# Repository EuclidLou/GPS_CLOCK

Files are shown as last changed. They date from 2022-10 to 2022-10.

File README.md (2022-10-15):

# GPS_CLOCK

## GPS授时的迷你时钟
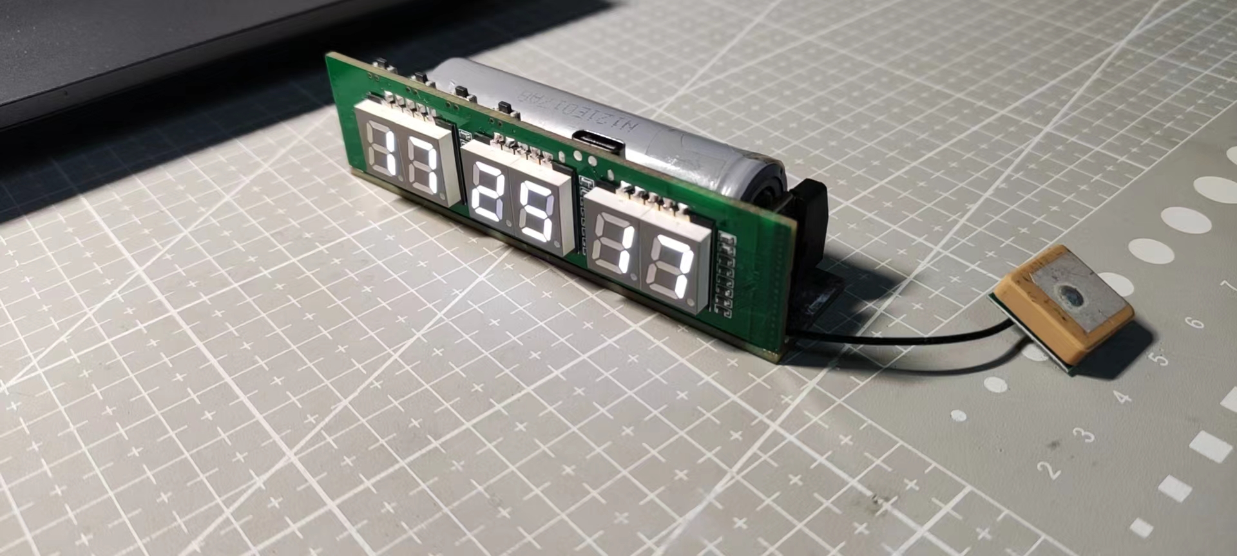
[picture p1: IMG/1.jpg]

## 前言
这是基地招新题目，怎么算成本都要100-200，不如做一个好看点的 <br>
板子的电池接口在两侧，之后会用弹簧连接电池仓 <br>

## 项目结构
|目录|内容|
|---|----|
|PCB_RELEASE|PCB|
|SOFTWARE|程序|
|CAD|外壳|

## 硬件部分
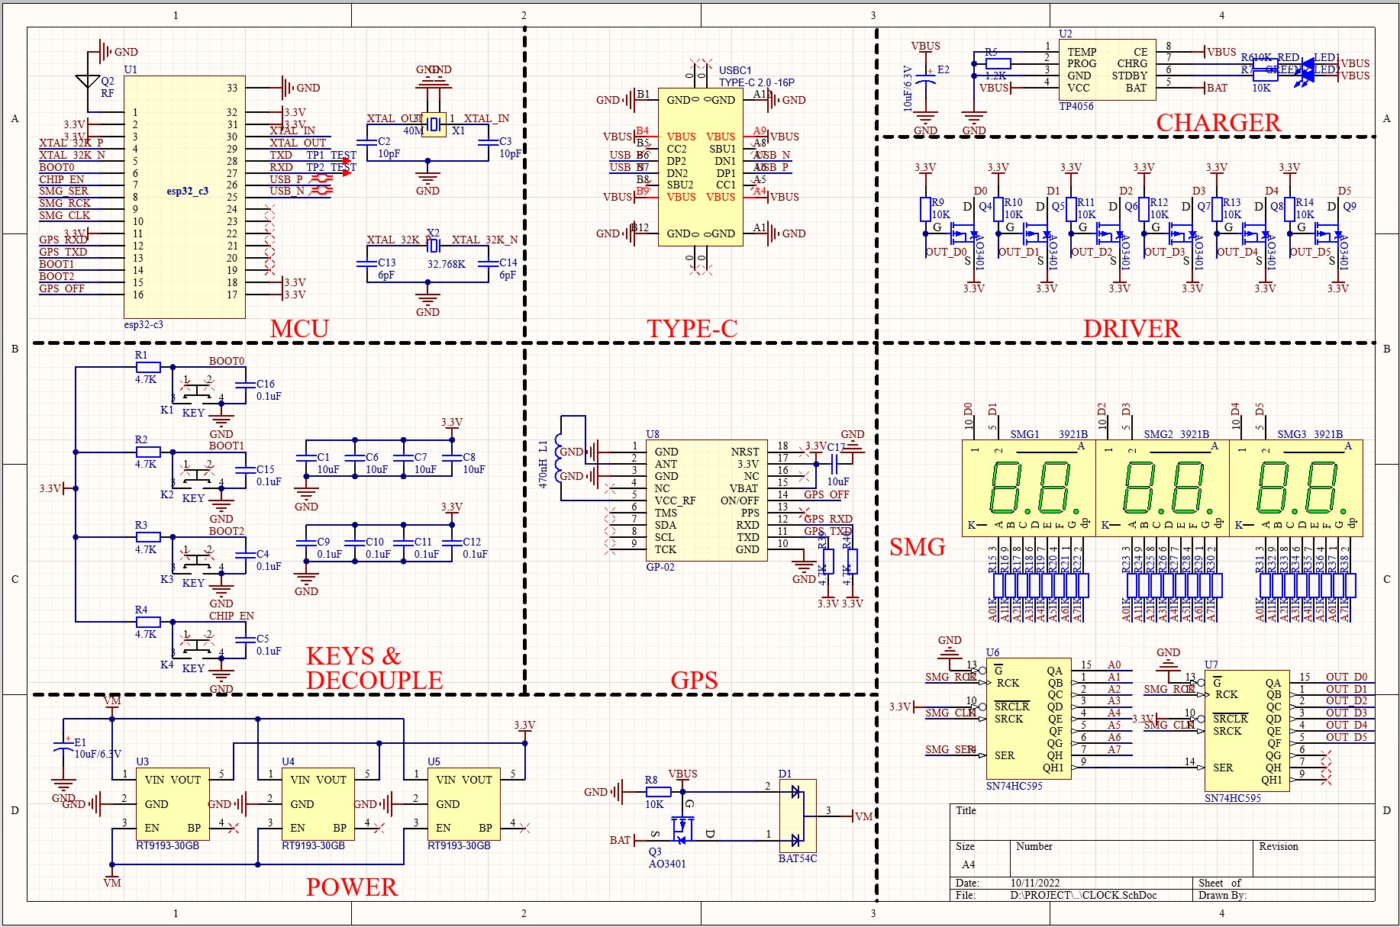
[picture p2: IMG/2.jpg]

主控依然使用ESP32-C3，GPS选用GP-02模块，数码管选了很久，找到了一家专门做贴片数码管的 <br>
译码器使用经典74HC595，担心输出功率不够，加了一级PMOS驱动 <br>
电源管理用的外置TYPE-C供电或一节18650，自动切换电源，并在外接电源时充电 <br>
按键从侧面引出四个，其中三个是可编程的，同时也是BOOT时的STRAPPER引脚(boot选择会自动锁存STRAPPER的值，因此可以复用) <br>
烧录方式通过ESP32内置的USB-JTAG桥，背面也留出了UART0的TEST POINT
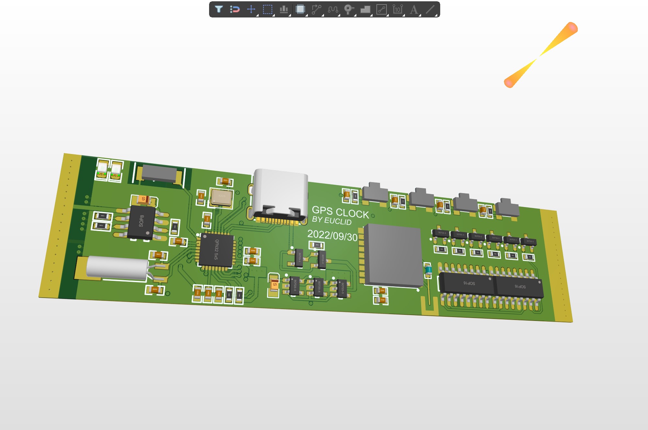
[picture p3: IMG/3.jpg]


## 软件部分
依然通过IDF编写，基于FreeRTOS建立3个线程 <br>
|Thread|Function|
|---|---|
|TaskA |显示时间|
|TaskB |校准时间|
|TaskC |菜单管理|

校准时间通过读取GP-02的 $GNZDA 字段，截取相应时间和日期 <br> 
实测室内冷启动校准耗时30s，热启动4s <br>
菜单正在完善，目前一级菜单KEY0切换显示 时间/日期 ，KEY1、KEY2调整亮度 <br>

## 机械部分
大致设计了一个外壳，把电池座和陶瓷天线都装进去 <br>
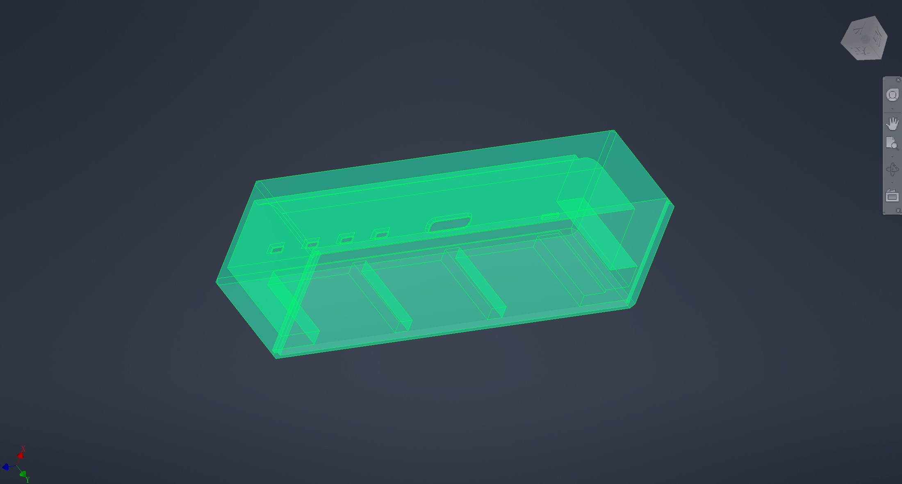
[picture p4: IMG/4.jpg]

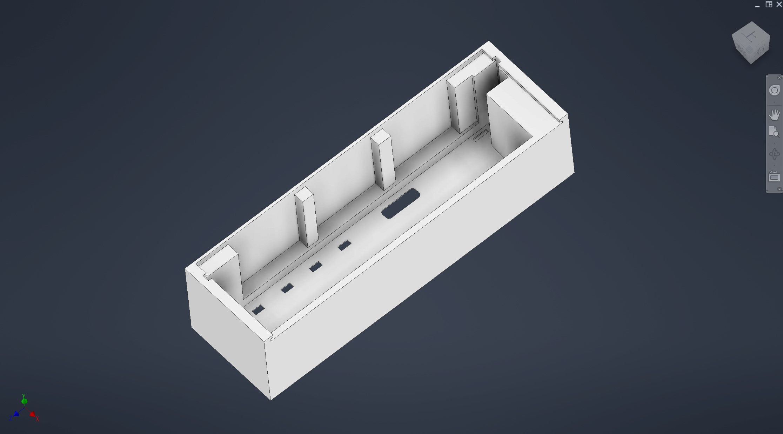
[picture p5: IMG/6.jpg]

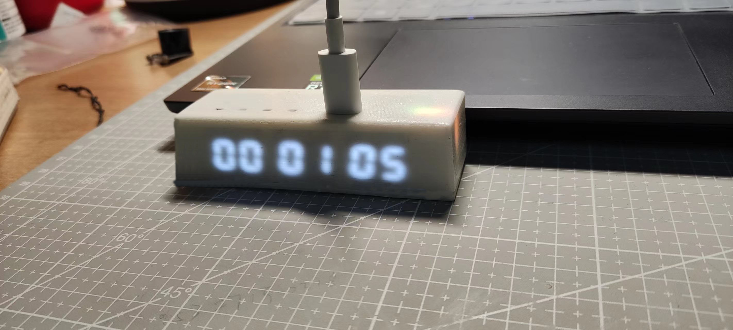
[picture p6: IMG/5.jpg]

外壳思路很美好，实际很拉跨，厚度小于宽度和长度，加上学校3D打印机粗糙的精度，极不符合人类审美，后续可能会改用较薄的锂电芯，并用亚克力板雕刻前后壳，形成三明治结构(或者没有后续，，)。

## 其他
### 关于LDO
ldo部分设计有错误，本来以为rt9193自带输出二极管，实际没有，故不可直接并联 <br>
单个9193可以提供300mA输出，不使用ESP32自带的射频则只需一只ldo
### 关于功耗
整机运行电流(bat端)为70mA左右，其中GPS为40mA，如果接受对时冷启动，满亮度常规运行功耗为30mA。使用18650(5000mAh)可待机约一周。

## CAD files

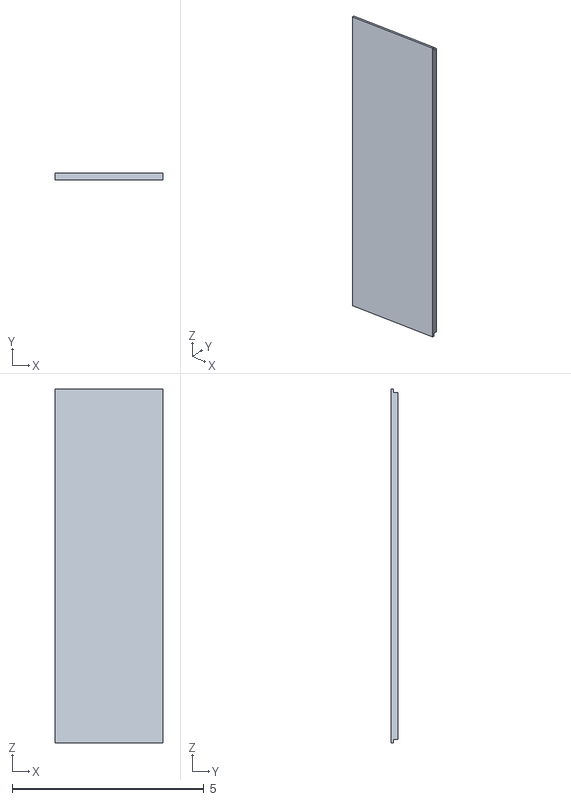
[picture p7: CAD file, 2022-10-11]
CAD/top.stl
2.82 x 0.18 x 9.22

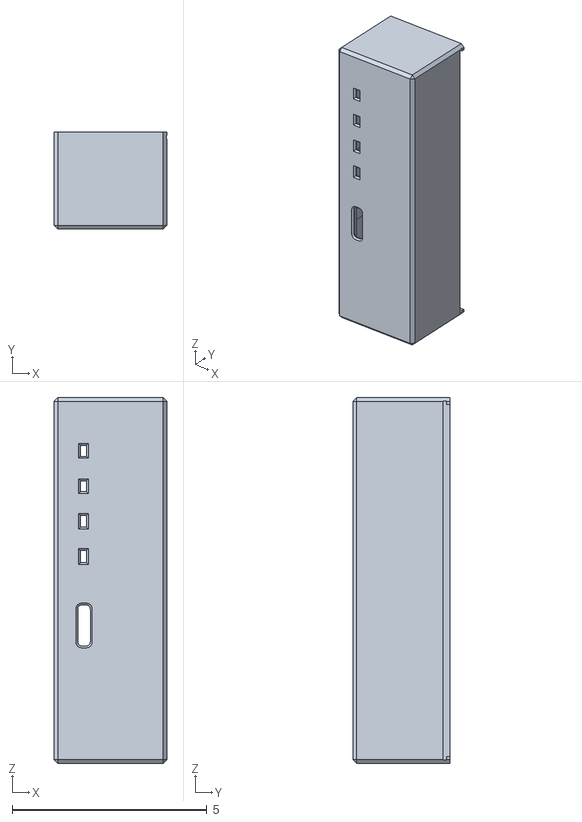
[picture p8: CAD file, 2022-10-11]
CAD/box.stl
2.90 x 2.50 x 9.40

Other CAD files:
CAD/box.ipt
CAD/comb.iam
CAD/top.ipt

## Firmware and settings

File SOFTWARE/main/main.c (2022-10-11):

#include <stdio.h>
#include <stdlib.h>
#include <string.h>
#include <time.h>
#include "driver/gpio.h"
#include "driver/uart.h"
#include "freertos/FreeRTOS.h"
#include "freertos/task.h"
#include "sys/time.h"
#include "esp_log.h"
#include "sdkconfig.h"
#include "driver/gptimer.h"
#include "clock_gpio.h"
#include "main.h"




void Atask(void *pvParameters) {
    uint16_t mode = 0;
    int bright_level = 0;
    time_t trans_time_sec;
    struct tm date_and_time = {0};

    for(;;) {
        xQueuePeek(mode_queue, &mode, 0);
        xQueuePeek(level_queue, &bright_level, 0);
        time(&trans_time_sec);
        localtime_r(&trans_time_sec, &date_and_time);

        if (mode == 0) {
            show_time(date_and_time.tm_hour, date_and_time.tm_min, date_and_time.tm_sec, bright_level);
        }
        else if (mode == 1) {
            show_time(date_and_time.tm_year, date_and_time.tm_mon + 1, date_and_time.tm_mday, bright_level);
        }
         
    }
}

void Btask(void *pvParameters) {
    TickType_t lastwaketime;
    lastwaketime = xTaskGetTickCount();

    time_t trans_time_sec;
    struct tm date_and_time;
    struct timeval val;
    date_and_time.tm_sec   = 0;
    date_and_time.tm_min   = 0;
    date_and_time.tm_hour  = 0;
    date_and_time.tm_year  = 0;
    date_and_time.tm_mon   = 0;
    date_and_time.tm_mday  = 0;
    date_and_time.tm_isdst= -1;

    int init_done = 0;
    int correct_done = 0;
    uint8_t data[1024];
    uint8_t time_data[6];
    uint8_t date_data[6];
    int length = 1024;

    for(int i=60; i>0; i--) { // initialize the time table at the reboot , set 60s timeout.
        length = uart_read_bytes(UART_NUM_1, data, length, 1000);
        for(int pos=0; pos<1000; pos++) {
            if((data[pos] == '$') && (data[pos+1] == 'G') && (data[pos+2] == 'N') && (data[pos+3] == 'Z') && (data[pos+4] == 'D') && (data[pos+5] == 'A') && (data[pos+6] == ',') && (data[pos+7] < 58) && (data[pos+8] > 47)) {
                // get current time
                time_data[0] = data[pos +  7];
                time_data[1] = data[pos +  8];
                time_data[2] = data[pos +  9];
                time_data[3] = data[pos + 10];
                time_data[4] = data[pos + 11];
                time_data[5] = data[pos + 12];
                // get current date
                date_data[0] = data[pos + 18];
                date_data[1] = data[pos + 19];
                date_data[2] = data[pos + 21];
                date_data[3] = data[pos + 22];
                date_data[4] = data[pos + 26];
                date_data[5] = data[pos + 27];
                date_and_time.tm_year = 2000 + (date_data[5]-48) + (10 * (date_data[4]-48)) - 1900;
                date_and_time.tm_mon = ((date_data[3]-48) + (10 * (date_data[2]-48))-1);
                date_and_time.tm_mday = ((date_data[1]-48) + (10 * (date_data[0]-48)));
                date_and_time.tm_sec = (time_data[5]-48) + (10 * (time_data[4]-48));
                date_and_time.tm_min = (time_data[3]-48) + (10 * (time_data[2]-48));
                date_and_time.tm_hour = (time_data[1]-48) + (10 * (time_data[0]-48));

                trans_time_sec = mktime(&date_and_time);
                val.tv_sec = trans_time_sec + 8*60*60; 
                val.tv_usec = 0;
                settimeofday(&val, NULL);
                init_done = 1;
                break;
            }
        }
        if(init_done == 1) {init_done = 0; break;}
        vTaskDelayUntil(&lastwaketime, 1000);
    }

    
    for(;;) { // main time correct loop: try to correct the time 5 times every day
        for(int try_time = 5; try_time>0; try_time--) {
            length = uart_read_bytes(UART_NUM_1, data, length, 1000);
            for(int pos=0; pos<1000; pos++) {
                if((data[pos] == '$') && (data[pos+1] == 'G') && (data[pos+2] == 'N') && (data[pos+3] == 'Z') && (data[pos+4] == 'D') && (data[pos+5] == 'A') && (data[pos+6] == ',') && (data[pos+7] < 58) && (data[pos+8] > 47)) {
                    // get current time
                    time_data[0] = data[pos +  7];
                    time_data[1] = data[pos +  8];
                    time_data[2] = data[pos +  9];
                    time_data[3] = data[pos + 10];
                    time_data[4] = data[pos + 11];
                    time_data[5] = data[pos + 12];
                    // get current date
                    date_data[0] = data[pos + 18];
                    date_data[1] = data[pos + 19];
                    date_data[2] = data[pos + 21];
                    date_data[3] = data[pos + 22];
                    date_data[4] = data[pos + 26];
                    date_data[5] = data[pos + 27];
                    date_and_time.tm_year = 2000 + (date_data[5]-48) + (10 * (date_data[4]-48)) - 1900;
                    date_and_time.tm_mon = ((date_data[3]-48) + (10 * (date_data[2]-48))-1);
                    date_and_time.tm_mday = ((date_data[1]-48) + (10 * (date_data[0]-48)));
                    date_and_time.tm_sec = (time_data[5]-48) + (10 * (time_data[4]-48));
                    date_and_time.tm_min = (time_data[3]-48) + (10 * (time_data[2]-48));
                    date_and_time.tm_hour = (time_data[1]-48) + (10 * (time_data[0]-48));

                    trans_time_sec = mktime(&date_and_time);
                    val.tv_sec = trans_time_sec + 8*60*60; 
                    val.tv_usec = 0;
                    settimeofday(&val, NULL);
                    correct_done = 1;
                    break;
                }
            }
            if(correct_done == 1){correct_done = 0; break;}
            vTaskDelayUntil(&lastwaketime, 1000);
        }
        vTaskDelayUntil(&lastwaketime, 1000*60*60*24);
    }
}

void Ctask(void *pvParameters) {
    TickType_t lastwaketime;
    lastwaketime = xTaskGetTickCount();
    uint16_t mode = 0;
    int bright_level = 0;
    xQueueSendToBack(mode_queue, &mode, 0);
    xQueueSendToBack(level_queue, &bright_level, 0);
    for(;;) {
        if(gpio_get_level(PIN_NUM_KEY0)==0) {
            xQueueReceive(mode_queue, &mode, 0);
            if(mode == 0) {mode = 1;}
            else {mode = 0;}
            xQueueSendToBack(mode_queue, &mode, 0);
            vTaskDelayUntil(&lastwaketime, 500);
        }
        if(gpio_get_level(PIN_NUM_KEY1)==0) {
            xQueueReceive(level_queue, &bright_level, 0);
            if(bright_level < 9) {bright_level ++;}
            xQueueSendToBack(level_queue, &bright_level, 0);
            vTaskDelayUntil(&lastwaketime, 200);
        }
        if(gpio_get_level(PIN_NUM_KEY2)==0) {
            xQueueReceive(level_queue, &bright_level, 0);
            if(bright_level > 0) {bright_level --;}
            xQueueSendToBack(level_queue, &bright_level, 0);
            vTaskDelayUntil(&lastwaketime, 200);
        }
        vTaskDelayUntil(&lastwaketime, 1);
    }
}

void app_main(void)
{
    gpio_init();
    mode_queue = xQueueCreate(1, sizeof(uint16_t));
    level_queue = xQueueCreate(1, sizeof(int));
    xTaskCreate(Atask, "SHOW THE NUM", 65536, NULL, 1, NULL);
    xTaskCreate(Btask, "GET THE TIME", 65536, NULL, 2, NULL);
    xTaskCreate(Ctask, "GET THE INTER", 65536, NULL, 3, NULL);
}

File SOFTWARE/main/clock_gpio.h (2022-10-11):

#define PIN_NUM_DS      3
#define PIN_NUM_ST      4
#define PIN_NUM_SH      5

#define PIN_NUM_TX      6
#define PIN_NUM_RX      7
#define PIN_NUM_GPSOFF  10

#define PIN_NUM_KEY0    2
#define PIN_NUM_KEY1    8
#define PIN_NUM_KEY2    9

#define SMG_A           (1<<0)
#define SMG_B           (1<<1)
#define SMG_C           (1<<2)
#define SMG_D           (1<<3)
#define SMG_E           (1<<4)
#define SMG_F           (1<<5)
#define SMG_G           (1<<6)
#define SMG_P           (1<<7)

#define SMG_BIT0        (1<<0)
#define SMG_BIT1        (1<<1)
#define SMG_BIT2        (1<<2)
#define SMG_BIT3        (1<<3)
#define SMG_BIT4        (1<<4)
#define SMG_BIT5        (1<<5)

#define SMG_0           (SMG_A | SMG_B | SMG_F | SMG_D | SMG_C | SMG_E)
#define SMG_1           (SMG_B | SMG_C)
#define SMG_2           (SMG_A | SMG_B | SMG_G | SMG_E | SMG_D)
#define SMG_3           (SMG_A | SMG_B | SMG_G | SMG_C | SMG_D)
#define SMG_4           (SMG_F | SMG_B | SMG_G | SMG_C)
#define SMG_5           (SMG_A | SMG_F | SMG_D | SMG_G | SMG_C)
#define SMG_6           (SMG_A | SMG_F | SMG_D | SMG_G | SMG_C | SMG_E)
#define SMG_7           (SMG_A | SMG_B | SMG_C)
#define SMG_8           (SMG_A | SMG_B | SMG_F | SMG_D | SMG_G | SMG_C | SMG_E)
#define SMG_9           (SMG_A | SMG_B | SMG_F | SMG_D | SMG_G | SMG_C)
